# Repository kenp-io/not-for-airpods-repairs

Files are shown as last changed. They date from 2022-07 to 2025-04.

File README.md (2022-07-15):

# The Not-for-AirPods Repairs Directory

The content of this repository is licensed under the [WTFPL License](http://www.wtfpl.net/). Please have a close look at the terms before using this material. I would really appreciate it if you do the right thing and at least provide a link to my [YouTube channel](https://www.youtube.com/c/exploringthesimulation), but it is not compulsory.

Nothing in this repository is part of Apple's Intellectual Property. Any resemblance to actual products or registered trademarks is entirely coincidental.

Want to contribute to the project? Make a pull request! Please note that only technical contributions will be merged (requests like typo fixing won't be).

Please don't hesitate to star the repo if you want to be updated on this project :)

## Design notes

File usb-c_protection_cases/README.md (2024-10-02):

# The Not-for-AirPods USB-C Protection Cases

Each folder contains the 3D files if you want to print your own version of the cases or need them for another reason.

The PCB schematics are always the same, so I won't include them here. You can find them in the *usb-c_internal_kits* folder located in the root of this repository. I don't think I will include any Gerber files or KiCad project for this, simply because it takes time to maintain and I found that nobody uses them since some chips are almost impossible to source without the right contact (that I sadly can't share for obvious reasons).

To secure the plastic parts together you will also need: 

- 2x M1.4 nuts. 
- 2x M1.4x5 screws (M1.4x4 for max_A2096). I use black powder coated DIN 912 screws.

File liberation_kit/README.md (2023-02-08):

# The Not-for-AirPods Liberation Kit

Repairs on the 1st and 2nd generation of *a certain model of wireless buds* cases are notoriously almost impossible. The white plastic shell will get damaged. What if instead of spending hours damaging that shell, we spend just 5 minutes carefully cutting it into two pieces. Then anything inside can be repaired (battery, Lightning connector, ...).

But then the white plastic shell will be useless?! Yes. And you can't buy a replacement part anywhere?! Yes.

This is what this folder is for. To give you that replacement part.

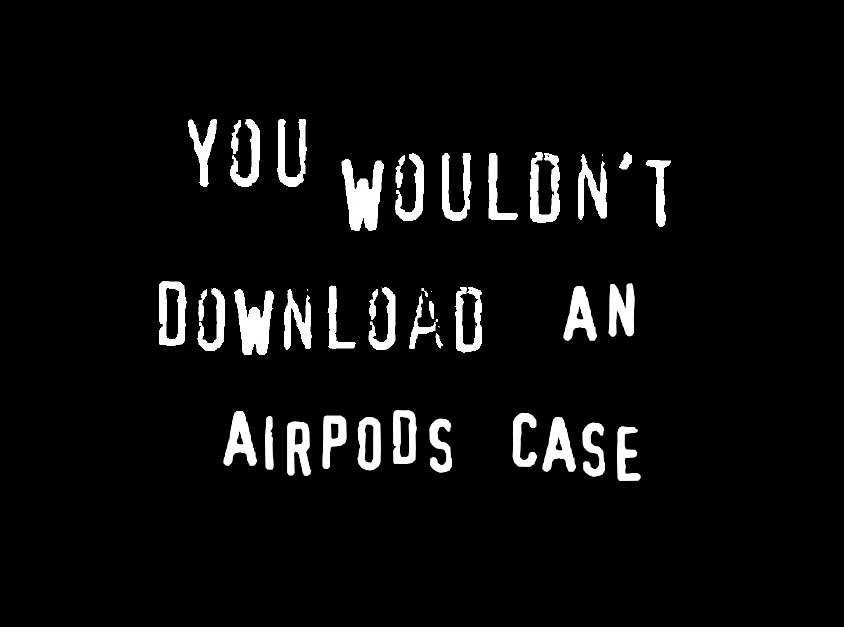
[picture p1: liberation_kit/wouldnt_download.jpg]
You wouldn't download an AirPods case


Yes, yes I would. If only I could...

## I'm lost?

File *liberation-gen1.stl* will fit the Gen. 1.

File *liberation-gen2.stl* will fit the Gen. 2 wireless. Non-wireless should also fit but I haven't tried it yet. Will update if I do.

File *liberation-pro.stl* will fit the Pro Gen. 1.

## How to install it?
### Gen.1 and 2:

I highly suggest you watch my video ([link](https://www.youtube.com/watch?v=RQqk45ps9kg)).

Cutting the case open is shown at 2:33.

Printing is shown at 3:06.

For best results I recommend you print with an SLA printer.

But, if you only have an FDM printer ("only"..., that's already awesome!) I would try printing anyway. If you don't like the quality and feel of it, I would suggest looking into printing it with ABS and then doing an acetone vapour bath ;)

### Pro Gen.1:

I will make a video myself, but for the moment you can watch this: ([link](https://www.youtube.com/watch?v=f53kpgHcVZs)).
You need to add two 1.4mm nuts at the bottom.w

## Improvements for the future:

- Waterproofing
- Adding some screw holes to easily open it up again
- Sky is the limit, really.

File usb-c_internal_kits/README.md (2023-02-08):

# The Not-for-AirPods USB-C Mod

Folder *flosspods_1_2_flex* contains the KiCad project if you want to order the PCB yourself. It works on Gen. 1 and Gen. 2 (both wired-only and wireless versions!). You need to generate the Gerber files yourself. There is an extra file called *flosspods_1_2_flex-stiffener.jpg*. It shows where I've placed the stiffener for the connector. It's nice to have but not a requirement. You send that file to the board house along with your Gerber files. Here it was sent to PCBWay.

File *bracket_1_2.dxf* is the metallic bracket I've ordered to be laser cut. It was cut in 0.5mm stainless steel.

File *sourcing.png* is a hint to find the source for the chips. I don't want to post those links. If you're smart enough to replicate this project, you're smart enough to find what you're looking for with this ;) If you can't find those chips, just use the same outline but adapt the circuit to the chips you found. Then you can make a pull request. Seems like a lot of effort, but if you want to learn there is no better way.

---

Folder *flosspods_pro_flex* contains the KiCad project if you want to order the PCB yourself. It works on model Pro Gen. 1 (M4g$af3 and non-M4g$af3). You need to generate the Gerber files yourself. There is an extra file called *flosspods_pro_flex-stiffener.jpg*. It shows where I've placed the stiffener for the connector. It's nice to have but not a requirement. You send that file to the board house along with your Gerber files. Here it was sent to PCBWay.

File *bracket_pro.dxf* is the metallic bracket I've ordered to be laser cut. It was cut in 0.5mm stainless steel.

## Improvements for the future:

- Move to a waterproof connector. This is very low priority as the 3D printed case from the liberation kit also needs to be waterproof... (done for pro!)
- Improve for mid-scale manufacturing run? (done for pro!)

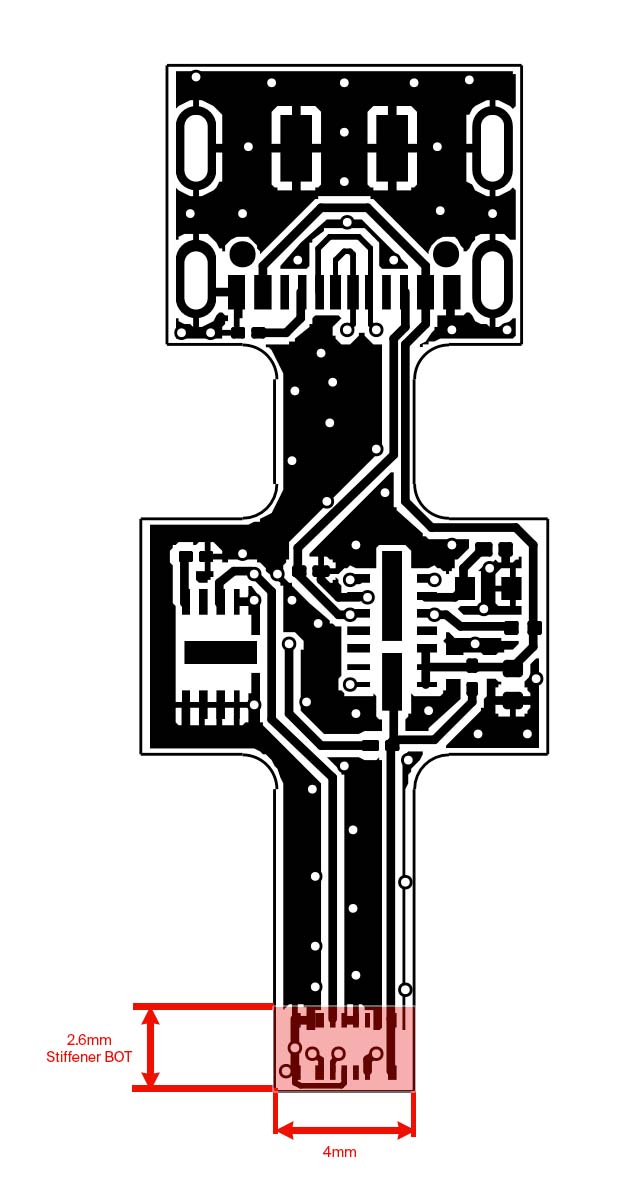
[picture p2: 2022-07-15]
usb-c_internal_kits/flosspods_1_2_flex/flosspods_1_2_flex-stiffener.jpg

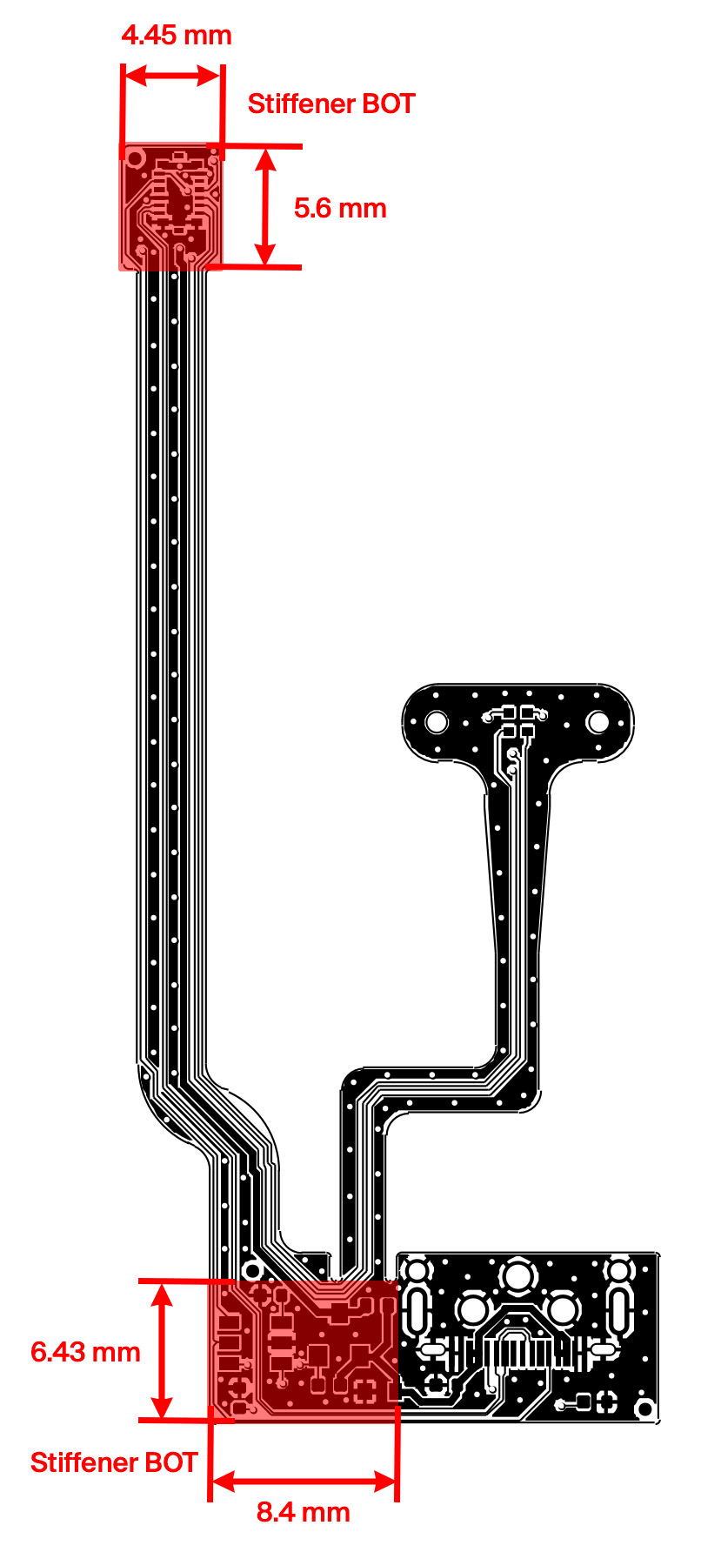
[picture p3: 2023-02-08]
usb-c_internal_kits/flosspods_pro_flex/flosspods_pro_flex-stiffener.jpg

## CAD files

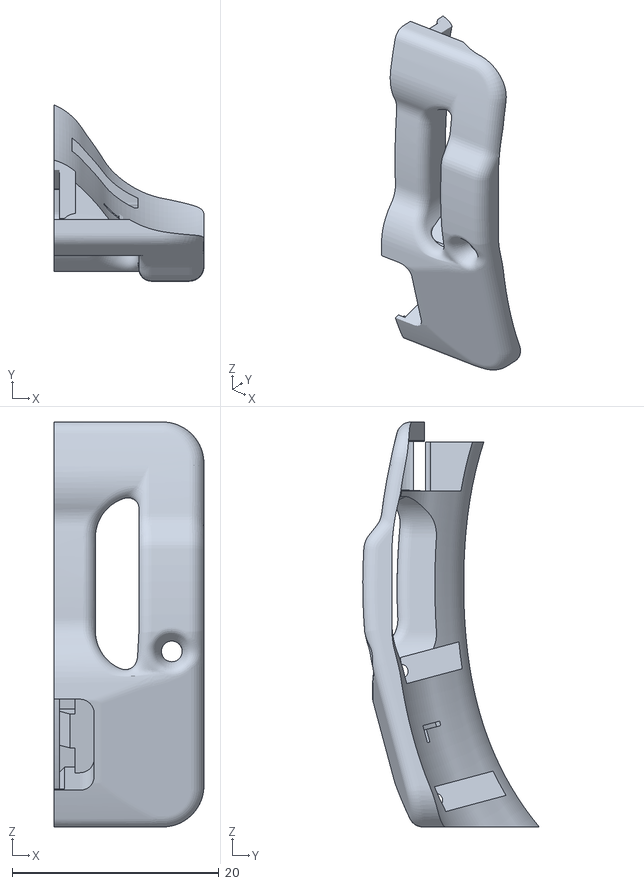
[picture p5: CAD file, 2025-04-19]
usb-c_protection_cases/max_A2096/max_A2096_MAIN_v7.stl
14.5 x 17.1 x 39.2

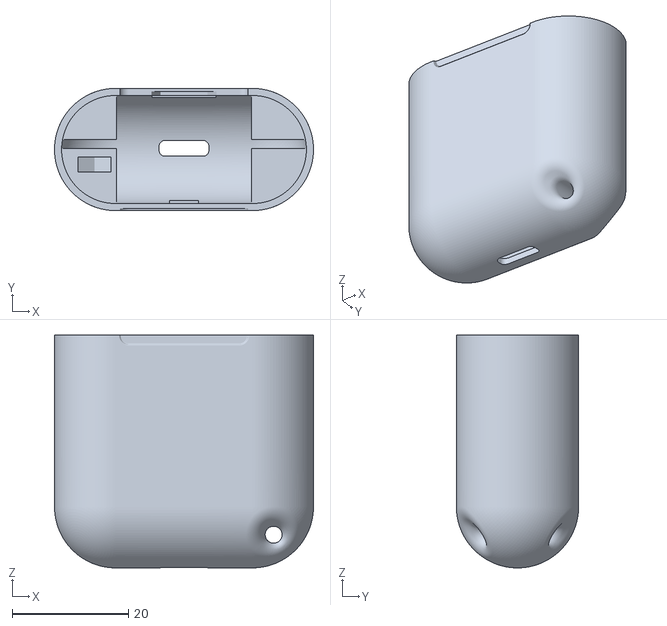
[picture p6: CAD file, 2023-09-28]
liberation_kit/liberation-gen1_V2.stl
44.5 x 21.0 x 40.0

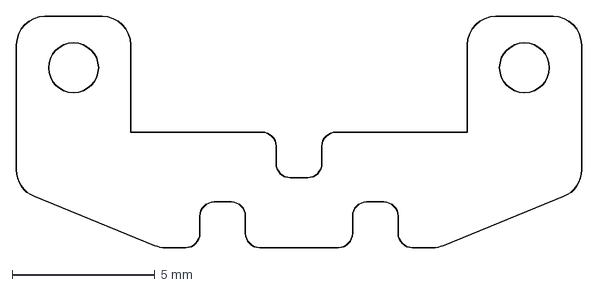
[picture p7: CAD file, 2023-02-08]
usb-c_internal_kits/bracket_pro.dxf
19.8 x 8.11 mm

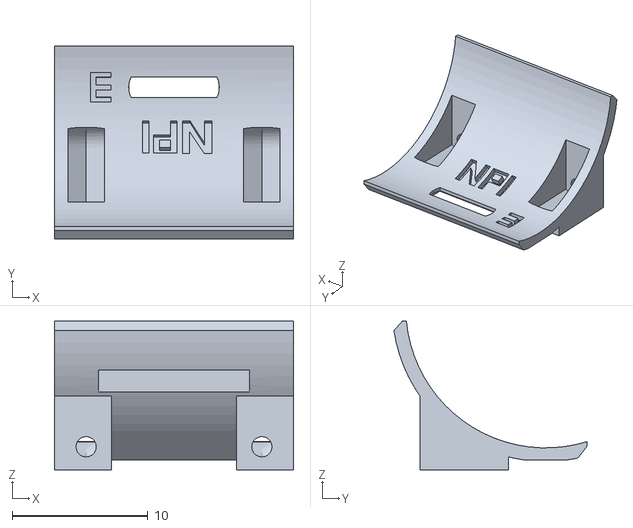
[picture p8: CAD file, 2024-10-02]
usb-c_protection_cases/non-pro-1_A1602/non-pro-1_A1602_HOLDER.stl
17.6 x 14.2 x 10.9

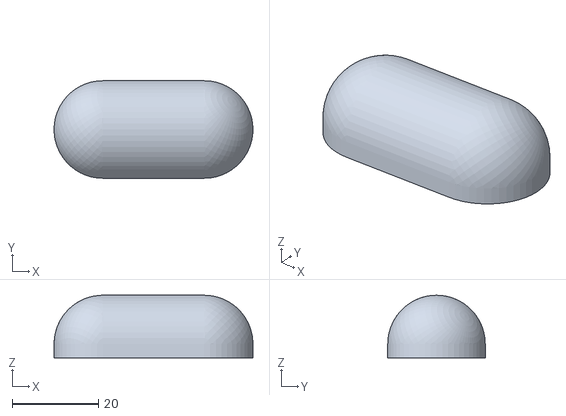
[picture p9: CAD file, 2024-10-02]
usb-c_protection_cases/non-pro-2_A1938/non-pro-2_A1938_TOP.stl
46.1 x 22.6 x 14.5

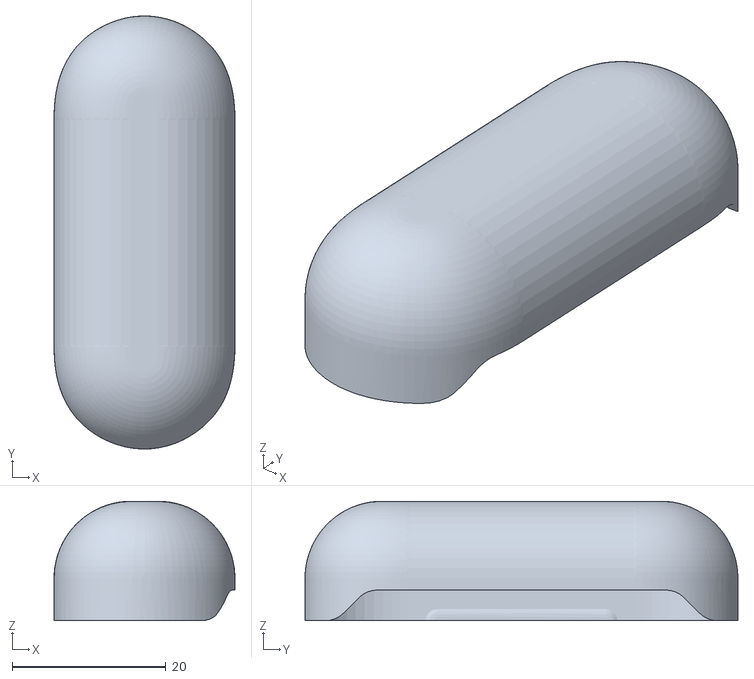
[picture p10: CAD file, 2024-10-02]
usb-c_protection_cases/non-pro-3_A2897_A2566/non-pro-3_A2897_A2566_TOP.stl
23.5 x 56.4 x 15.6

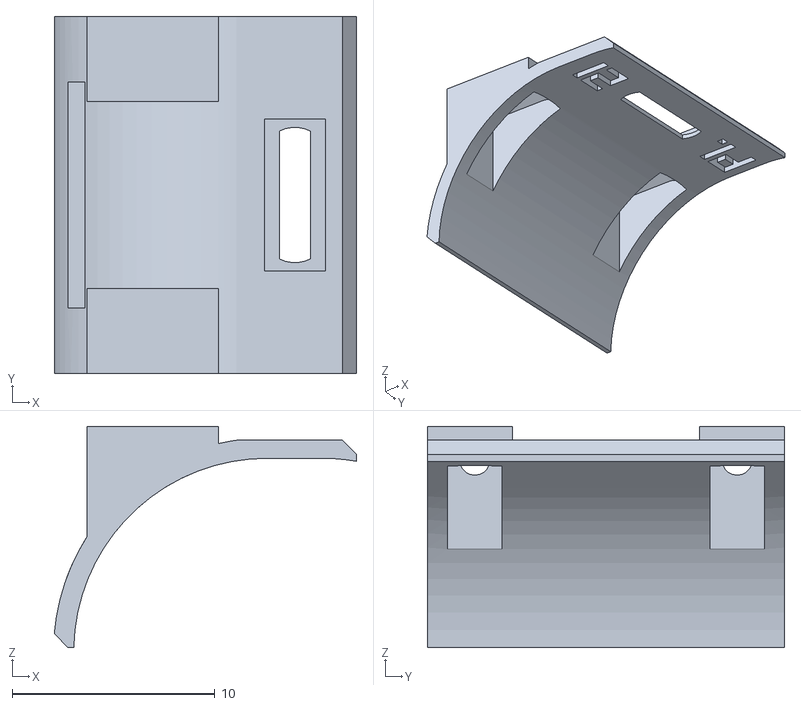
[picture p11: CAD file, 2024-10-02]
usb-c_protection_cases/pro-1_A2190/pro-1_A2190_HOLDER.stl
14.9 x 17.6 x 10.9

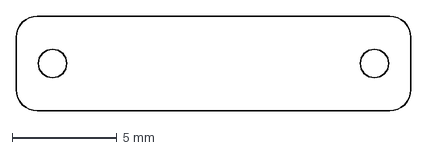
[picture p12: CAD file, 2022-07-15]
usb-c_internal_kits/bracket_1_2.dxf
18.8 x 4.50 mm

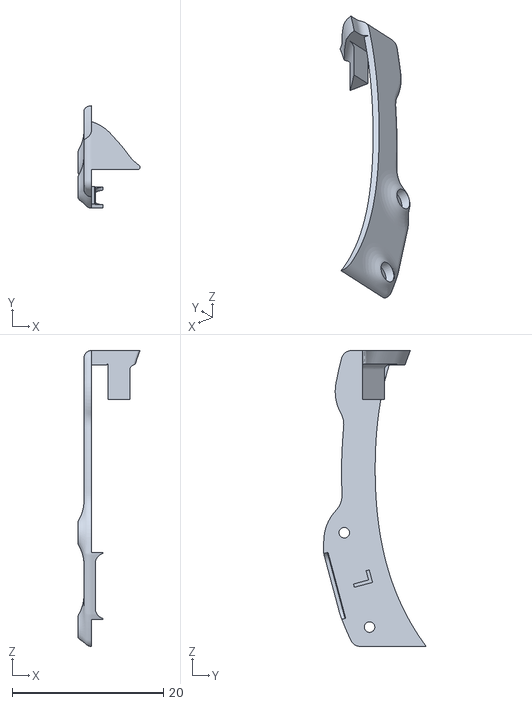
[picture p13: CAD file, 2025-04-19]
usb-c_protection_cases/max_A2096/max_A2096_COVER_v7.stl
8.24 x 13.6 x 39.2

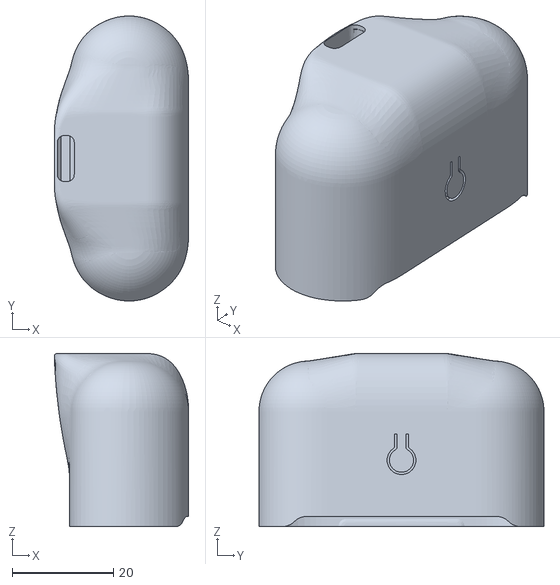
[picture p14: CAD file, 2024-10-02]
usb-c_protection_cases/non-pro-3_A2897_A2566/non-pro-3_A2897_A2566_BOTTOM.stl
26.6 x 56.4 x 34.2

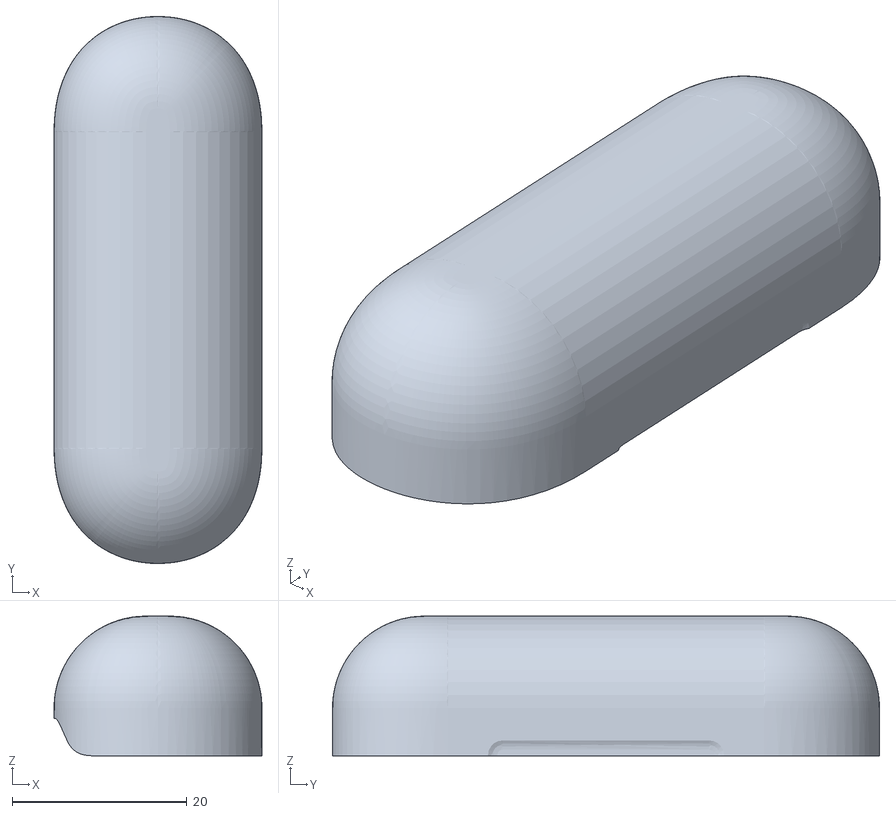
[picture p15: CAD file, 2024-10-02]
usb-c_protection_cases/pro-1_A2190/pro-1_A2190_TOP.stl
23.8 x 62.6 x 16.0

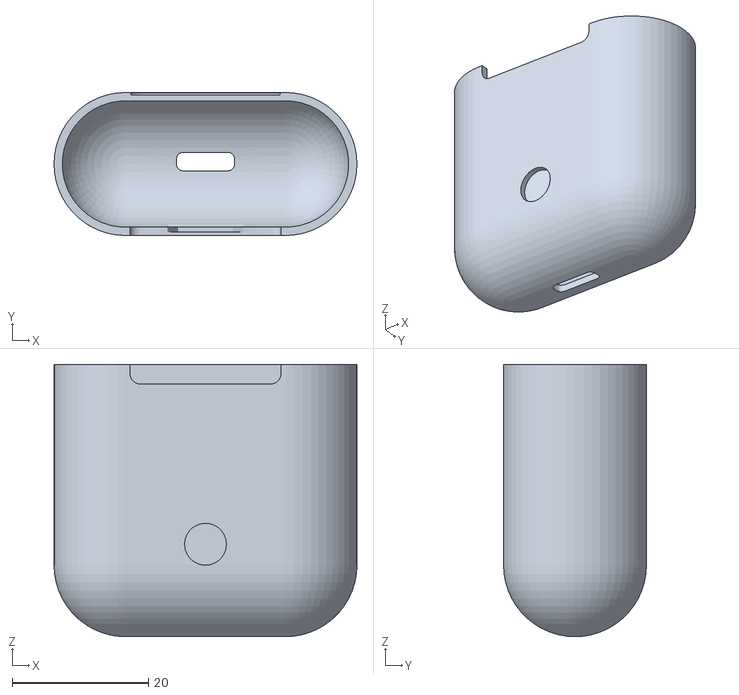
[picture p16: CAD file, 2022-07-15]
liberation_kit/liberation-gen1.stl
44.5 x 21.0 x 40.0

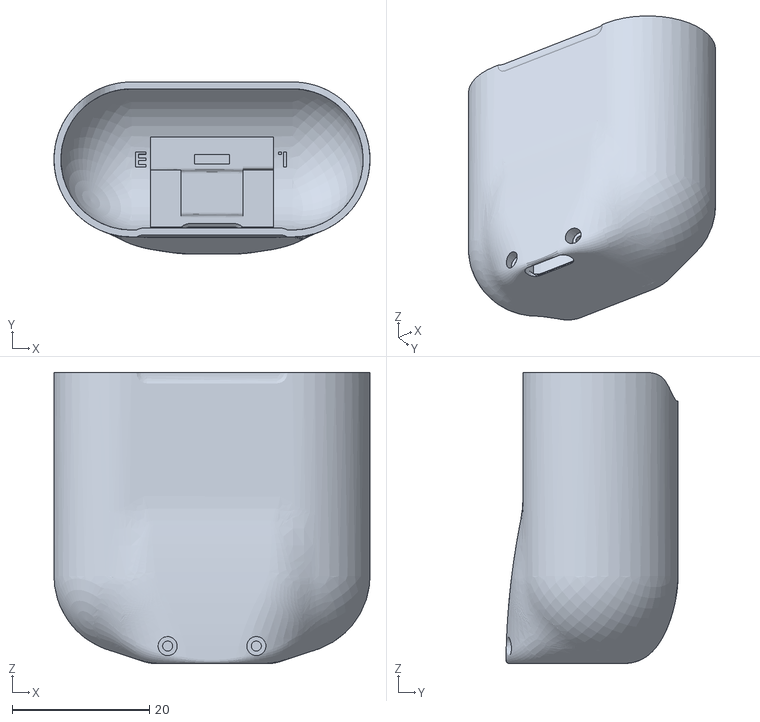
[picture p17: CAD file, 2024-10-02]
usb-c_protection_cases/non-pro-1_A1602/non-pro-1_A1602_BOTTOM.stl
46.1 x 25.1 x 42.5

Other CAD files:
usb-c_protection_cases/pro-2_A2700/pro-2_A2700_HOLDER.stl
liberation_kit/liberation-gen2_V2.stl
usb-c_protection_cases/non-pro-2_A1938/non-pro-2_A1938_HOLDER.stl
liberation_kit/liberation-gen2.stl
usb-c_protection_cases/max_A2096/max_A2096_COVER.stl
usb-c_protection_cases/max_A2096/max_A2096_MAIN.stl
usb-c_protection_cases/max_A2096/old_revisions/max_A2096_COVER_v4.stl
usb-c_protection_cases/max_A2096/old_revisions/max_A2096_MAIN_v4.stl
usb-c_protection_cases/non-pro-2_A1938/non-pro-2_A1938_BOTTOM.stl
usb-c_protection_cases/non-pro-3_A2897_A2566/non-pro-3_A2897_A2566_HOLDER.stl
usb-c_protection_cases/pro-1_A2190/pro-1_A2190_BOTTOM.stl
usb-c_protection_cases/pro-2_A2700/pro-2_A2700_BOTTOM.stl

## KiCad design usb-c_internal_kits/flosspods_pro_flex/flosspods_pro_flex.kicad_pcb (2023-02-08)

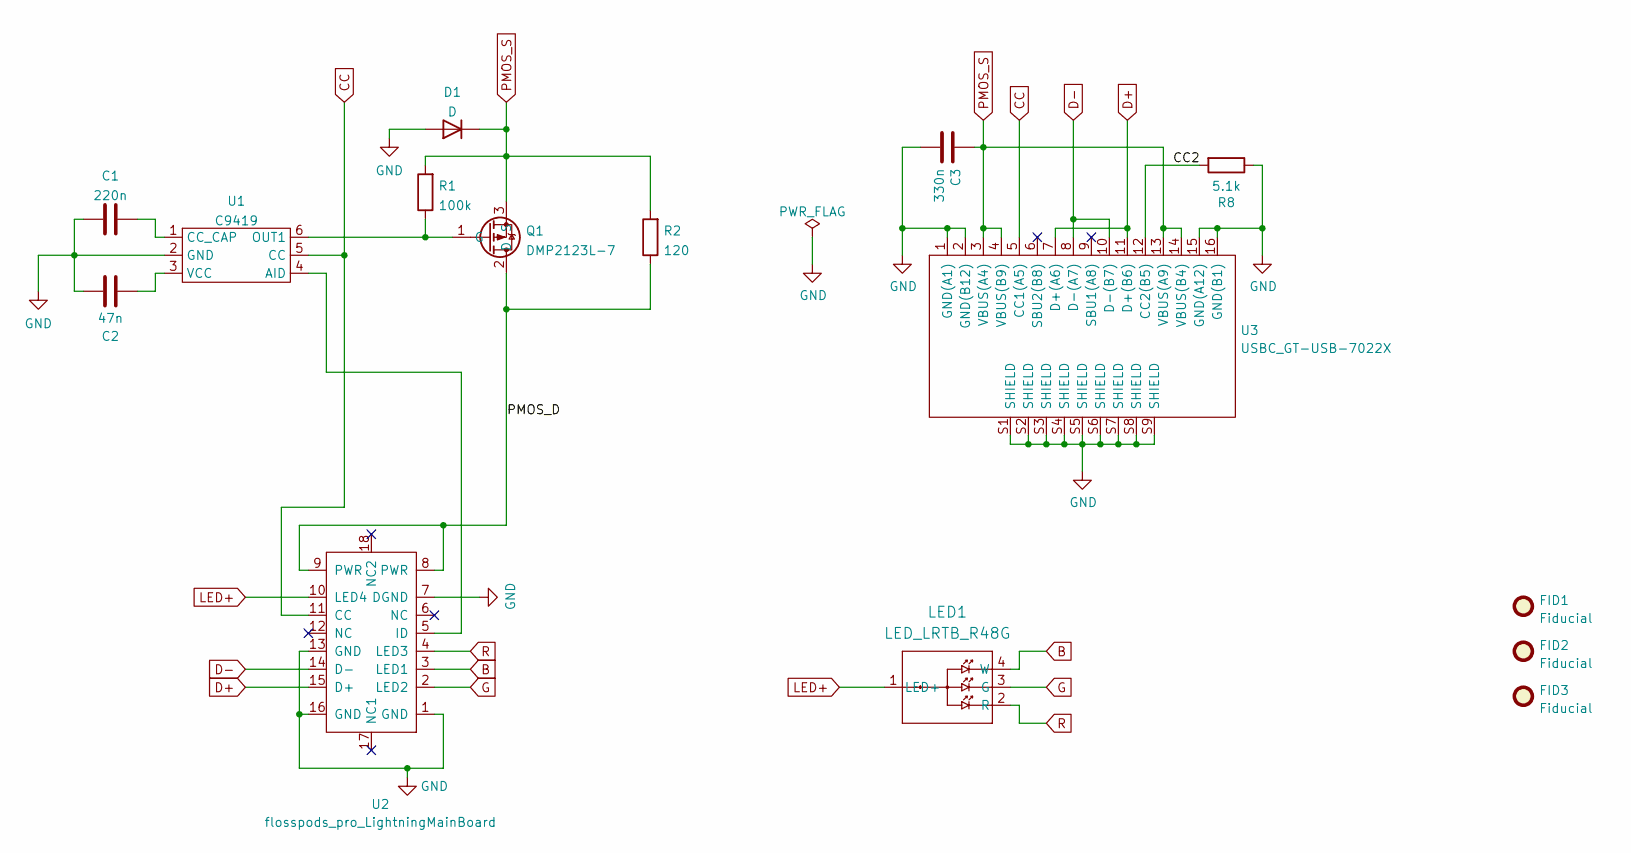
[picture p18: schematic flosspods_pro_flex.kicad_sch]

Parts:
C1: 220n; C_0402_1005Metric
C2: 47n; C_0402_1005Metric
C3: 330n; C_0402_1005Metric
D1: D; D_SOD-523
FID1, FID2, FID3: Fiducial; Fiducial_0.5mm_Mask1mm
LED1: LED_LRTB_R48G
Q1: DMP2123L-7
R1: 100k; R_0402_1005Metric
R2: 120; R_0402_1005Metric
R8: 5.1k; R_0402_1005Metric
U1: C9419
U2: flosspods_pro_LightningMainBoard
U3: USBC_GT-USB-7022X

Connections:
/CC2: R8.2, U3.12 (CC2(B5))
/PMOS_D: Q1.2 (D), R2.1, U2.8 (PWR), U2.9 (PWR)
B: LED1.4 (W), U2.3 (LED1)
CC: U1.5 (CC), U2.11 (CC), U3.5 (CC1(A5))
D+: U2.15 (D+), U3.7 (D+(A6)), U3.11 (D+(B6))
D-: U2.14 (D-), U3.8 (D-(A7)), U3.10 (D-(B7))
G: LED1.3 (G), U2.2 (LED2)
GND: C1.1, C2.2, C3.2, D1.2 (A), R8.1, U1.2 (GND), U2.1 (GND), U2.7 (DGND), U2.13 (GND), U2.16 (GND), U3.1 (GND(A1)), U3.2 (GND(B12)), U3.15 (GND(A12)), U3.16 (GND(B1)), U3.S1 (SHIELD), U3.S2 (SHIELD), U3.S3 (SHIELD), U3.S4 (SHIELD), U3.S5 (SHIELD), U3.S6 (SHIELD), U3.S7 (SHIELD), U3.S8 (SHIELD), U3.S9 (SHIELD)
LED+: LED1.1 (LED+), U2.10 (LED4)
unnamed: C1.2, U1.1 (CC_CAP)
unnamed: C2.1, U1.3 (VCC)
unnamed: Q1.1 (G), R1.1, U1.6 (OUT1)
unnamed: U1.4 (AID), U2.5 (ID)
PMOS_S: C3.1, D1.1 (K), Q1.3 (S), R1.2, R2.2, U3.3 (VBUS(A4)), U3.4 (VBUS(B9)), U3.13 (VBUS(A9)), U3.14 (VBUS(B4))
R: LED1.2 (R), U2.4 (LED3)

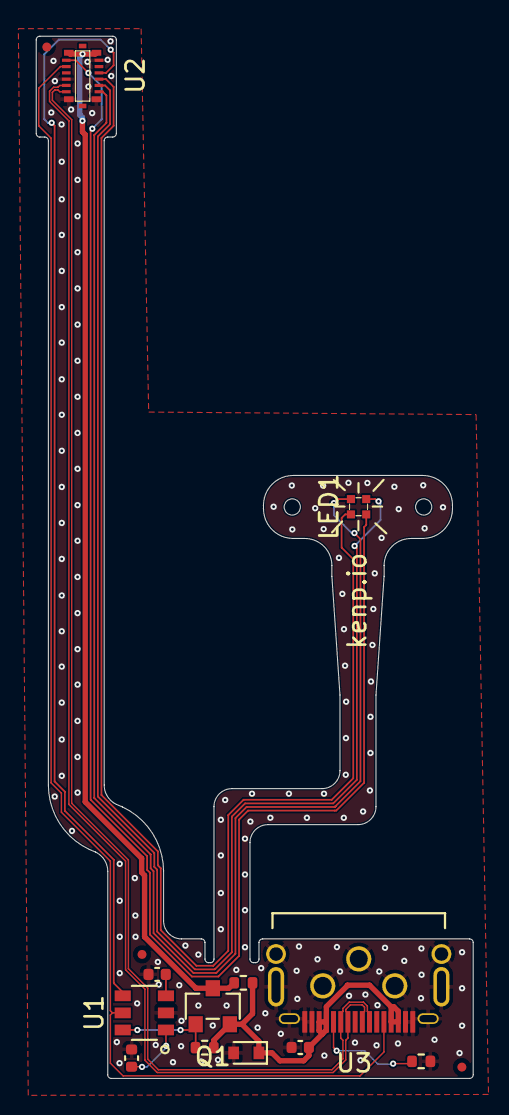
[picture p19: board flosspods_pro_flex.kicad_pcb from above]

Board: 2 copper layers, 24.3 x 57.9 mm, 15 parts (0 on the bottom side), 15 nets.

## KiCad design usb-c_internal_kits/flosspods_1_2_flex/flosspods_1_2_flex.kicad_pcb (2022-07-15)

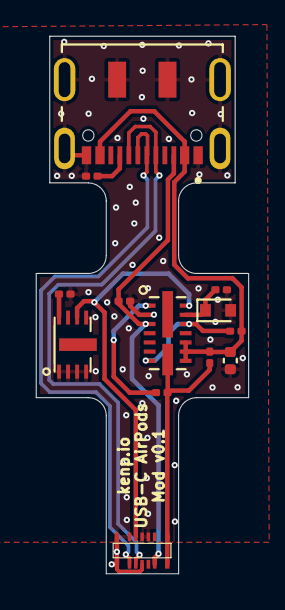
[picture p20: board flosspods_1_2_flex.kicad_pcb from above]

Board: 2 copper layers, 11.8 x 29.9 mm, 13 parts (0 on the bottom side), 12 nets.

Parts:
C1: 1 uF; C_0201_0603Metric
C2: 10 nF; C_0201_0603Metric
C3: 330 nF; C_0402_1005Metric
D1: D; D_SOD-523
R1: 150; R_0201_0603Metric
R2: 100k; R_0201_0603Metric
R3: 1k; R_0201_0603Metric
R4, R5: 5.1k; R_0201_0603Metric
U1: AS3616Afake
U2: flosspods_1_2_LightningMainBoard
U3: PD006
U4: JAE_DX07S016JA1R1500

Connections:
/PWR: R1.1, R3.1, U1.F2, U2.1 (VCC), U2.14 (VCC)
CC: R4.1, U1.3, U2.13 (CC), U4.3 (CC1(A5))
D+: U2.9 (D+), U4.6 (D+(A6)), U4.7 (D+(B6))
D-: U2.10 (D-), U4.5 (D-(B7)), U4.8 (D-(A7))
GND: C1.1, C2.2, C3.1, D1.2 (A), R4.2, R5.1, U1.2, U2.3 (GND), U2.4 (GND), U2.6 (NC), U2.7 (GND), U2.8 (GND), U2.11 (GND), U3.1, U3.2, U3.3, U3.4, U3.5, U4.1 (GND(A1/B12)), U4.12 (GND(A12/B1)), U4.S1 (SHIELD), U4.S2 (SHIELD), U4.S3 (SHIELD), U4.S4 (SHIELD), U4.S5 (SHIELD), U4.S6 (SHIELD)
unnamed: C1.2, D1.1 (K), U1.13
unnamed: C2.1, U3.8
unnamed: R5.2, U4.9 (CC2(B5))
unnamed: R2.1, U1.7, U1.12
unnamed: R3.2, U1.1
unnamed: U1.14, U2.5 (ID), U3.6
VCC: C3.2, R1.2, R2.2, U1.8, U1.9, U1.10, U4.2 (VBUS(A4/B9)), U4.11 (VBUS(B4/B9))

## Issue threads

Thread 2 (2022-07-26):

What resin do you use?

christiangenco, 2022-07-26:
In your [AirPods' Dirty Secret video](https://www.youtube.com/watch?v=RQqk45ps9kg) you SLA print with a white resin that ends up looking really close to the actual Airpods shiny white plastic.

What's that resin called and where did you buy it?

aimerib, 2022-07-27:
From the looks on the bottle, it looks like an ANYCUBIC 3D Printer Resin white, which would make sense since the SLA printer is also an anycubic.

Maybe this: https://www.amazon.com/ANYCUBIC-UV-Curing-Precision-Excellent-Fluidity/dp/B07G34K22M/
(Link for picture references. There are probably better places to get this resin from)

kenp-io, 2022-10-16:
What @aimerib said! Sourcing depends on where you're from. It won't look like the original AirPods case, I had to paint it. Might as well go crazy and embrace a different color :)

Closed 2022-10-16.

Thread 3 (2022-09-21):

Any future plans to make an stl for the airpods pro case?

printd3v, 2022-09-21:
Just repaired my airpods pro, had to sacrifice the wireless charger but it does still work... can't seem to find a shell stl for it and I can't really design it since I've trashed the case.

krupal157, 2022-10-11:
I have the case if you want but it has some texture on it, i can send you a link if you want to buy it.
i made mine in solid (925) silver.
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

kenp-io, 2022-10-16:
@printd3v Yes, they are coming! Will be released at the same time as USB-C replacement part.
@krupal157 Looks cool. Surely you can roll back the CAD file before texture was added? You can make a pull request and share it, I'm sure people will appreciate it.

MrFrio, 2022-11-21:
So can the pros be taken out the same way the 1st and 2nd gen AirPods can?

Closed 2022-10-16.

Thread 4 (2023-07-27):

schematics as pdf

mrx23dot, 2023-07-27:
please add it as pdf too.

kenp-io, 2023-07-31:
not an issue, if you need a pdf file you can generate/export one yourself.

Closed 2023-07-31.

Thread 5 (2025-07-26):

Circuit for usbc protection case

ErBWs, 2025-07-26:
Hi! I'm AirPods Pro 1 user from China, Since it takes a long time for the case to travel to China, I want to build the whole case by myself.

The chips and the specific lightning connector are easy to find in China but I cannot find the Kicad project for the cases, so will the circuit be released in the future?

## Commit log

2022-07-15 initial push
    [flosspods_1_2_flex.kicad_pcb, flosspods_1_2_flex.kicad_sch, flosspods_1_2_flex.sch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]
2022-07-15 extra info
    [bracket_1_2.dxf]
2023-02-08 added Pro model
    [bracket_pro.dxf, flosspods_pro_flex.kicad_pcb, flosspods_pro_flex.kicad_sch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]
2023-09-28 v2 3D parts
    [liberation-gen1_V2.stl, liberation-gen2_V2.stl]
2024-10-02 folder cleanup
    [bracket_1_2.dxf, bracket_pro.dxf, flosspods_1_2_flex.kicad_pcb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]
2024-10-02 ini protection cases
    [max_A2096_COVER.stl, max_A2096_MAIN.stl, non-pro-1_A1602_BOTTOM.stl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]
2025-04-19 max v7 added
    [max_A2096_COVER_v4.stl, max_A2096_COVER_v7.stl, max_A2096_MAIN_v4.stl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]
